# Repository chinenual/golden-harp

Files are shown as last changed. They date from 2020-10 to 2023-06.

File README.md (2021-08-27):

An updated interface to [Iasos's](https://iasos.com/)
["Golden Harp"](https://www.youtube.com/watch?v=cd00t0UGsC0).

The golden harp hardware was built by a now-defunct company named
UME.  It consisted of a small keyboard with two touch
sensitive strips which the musician can stroke like strumming a harp.
Output from this controller was fed through a proprietary serial
connection to a Commodore 64 where the signals were mapped to MIDI
notes with configurable key, octave and scale settings.

This project replaces the C64 based processing with an Arduino based
adapter.  Scales can be configured and uploaded to the adapter via a
Windows application (which need not be connected to the adapter during
performance). 

Thanks to Don Miller (@no-carrier) for reverse engineering the serial 
interface to the harp controller and creating the first Arduino implementation
to validate the controller serial interface.

Original implementation was a Commodore 64 program by Richard Wolton whose 
source code is lost in the mists of time.

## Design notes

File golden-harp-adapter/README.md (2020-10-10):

The Arduino device reads serial data from the harp controller (keyboard) and converts it to MIDI.

In performance mode, it need not be connected to a Windows machine; the USB port can be used as its power supply.

Notes pressed on either of the touch sensitive strips are converted to MIDI note on/off events at a fixed velocity of 64. The note conversion depends on the active key/scale/octave settings.

Those settings are selected from whatever presets are loaded and which can be changed via the keyboard on the controller.

In the studio, the Windows-based scale-manager.exe can connect through the USB port to configure scale presets.

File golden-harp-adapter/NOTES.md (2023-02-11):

Serial port names on Steve's mac:

board2: /dev/cu.usbserial-AG0JV596 (first box sent to Iasos)
board3: /dev/cu.usbserial-AG0JV6J0 (second box sent to Iasos)
board4: /dev/cu.usbserial-AG0JV27K (spare board for testing/support)
uno:    /dev/cu.usbserial-AL05OC8S (prototype)

Required libraries:
    ArduinoJson.h - https://arduinojson.org/
    SendOnlySoftwareSerial.h - https://github.com/nickgammon/SendOnlySoftwareSerial

Arduino IDE setup for firmware upload: 
    Tools->Board Arduino Nano
    Tools->Processor ATmega328P (Old bootloader)

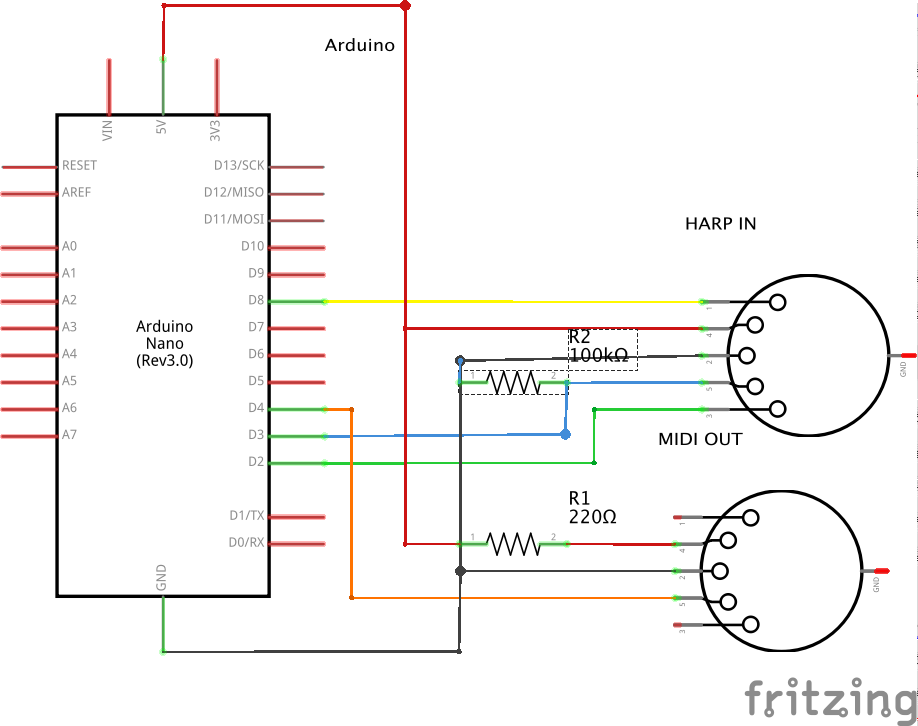
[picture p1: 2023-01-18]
golden-harp-adapter/nano-schematic_schem.png

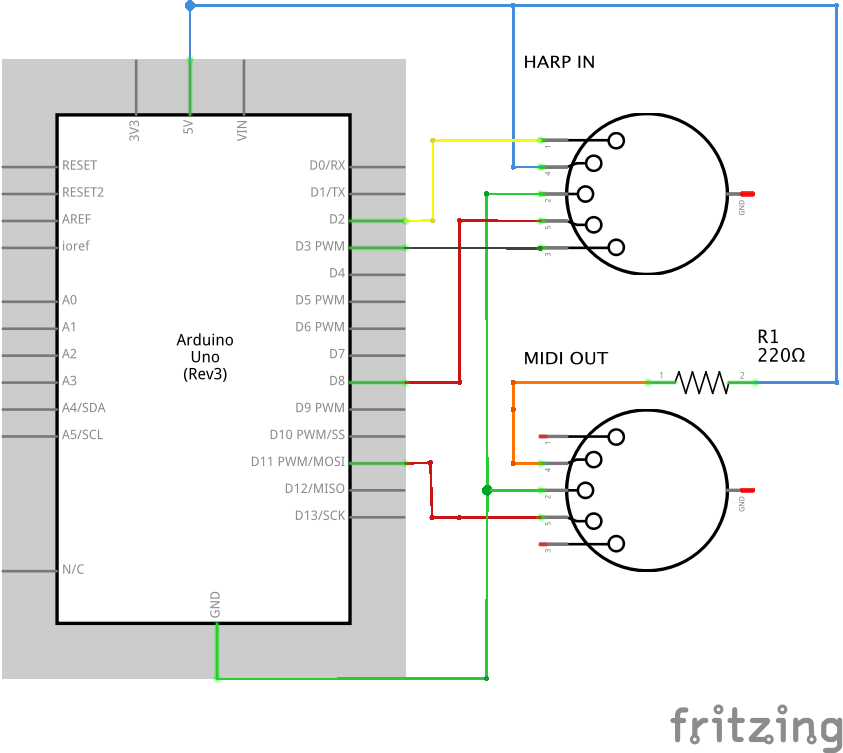
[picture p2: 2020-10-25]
golden-harp-adapter/uno-schematic.png

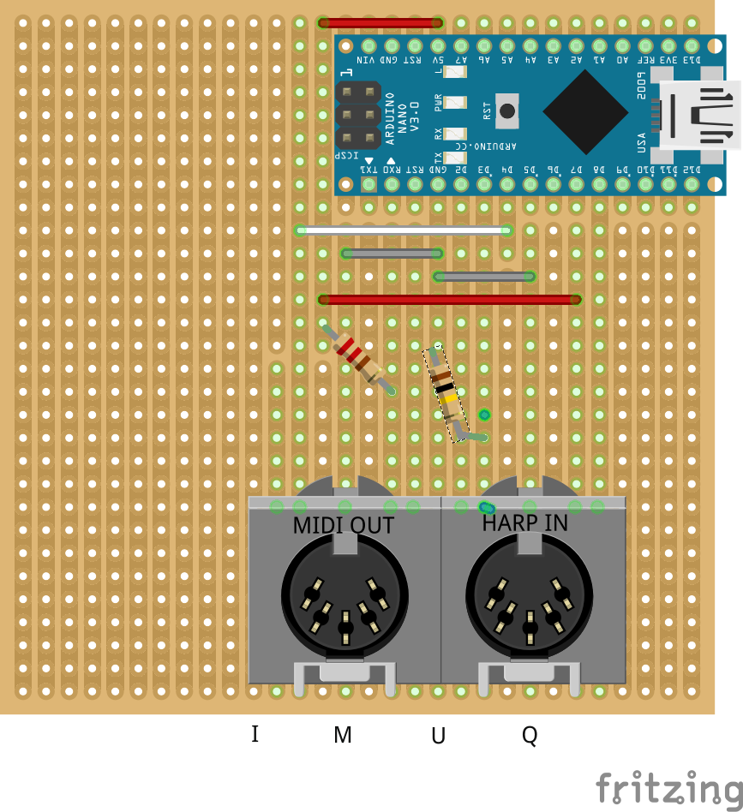
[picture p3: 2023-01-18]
golden-harp-adapter/stripboard_bb.png

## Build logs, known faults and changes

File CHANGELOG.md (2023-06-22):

## 1.5.1

Manager:

* Removes excessive delay on command read loop (speeds up setconfig considerably)

## 1.5.0

Manager:

* Reinitializes presets and scales vectors when reading a new config file.
* adds explicit error checks for JSON "status: ERROR" responses.

## 1.4.1

Adapter:

* Fixes the firmware upload script and re-versions the firmware

## 1.4.0

Manager:

* adds support for the new minnotelen param

Adapter:

* Added a pull down resistor to the Harp In serial connection
* min_note_length_ms parameter

## 1.3.0

Manager:

* Adds support for enabling debugging on the arduino 
* Serial config is now async via a goroutine so we can consume DEBUG stream
* Changes Excel parser from github.com/360EntSecGroup-Skylar/excelize to  github.com/uxri/excelize/v2 
 
 Adapter:
 
* Verbose debug mode

## 1.2.0

Manager:

* Invert the order of the presets in the Config XLS file to match the way Iasos views them when playing
* Tolerate presets in any order (use the Preset column to specify the preset number)

## 1.1.0

Manager:

* Support for new timing settings

Adapter: 

* make loop time and max_note_length_ms times configurable via the Manager

## 1.0.0

First release

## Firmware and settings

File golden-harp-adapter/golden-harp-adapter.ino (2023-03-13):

// pins for Harp Controller Keyboard DIN connector, left to right, back view, tab on top
// Nano/Stripboard version:
// 1 = D8 (DIN pin 1) LATCH
#define KBD_LATCH_PIN 8
// 2 = 5V   (DIN pin 4) 5V
// 3 = GND  (DIN pin 2) GND
// 4 = D3 (DIN pin 5) READ
#define KBD_READ_PIN 3
// 5 = D2 (DIN pin 3) CLOCK
#define KBD_CLOCK_PIN 2

// pins for the MIDI OUT connection, again, left to right, back view, tab on top
// Nano/Stripboard version:
// 2 = 5V  (DIN pin 4)  5V (via 220ohm resistor)
// 3 = GND (DIN pin 2)  GND 
// 4 = D4 (DIN pin 5)   DATA
#define MIDI_TX_PIN 4

#define CONFIG_IN_EEPROM 1
#define DEBUG_INPUT 0
#define VERBOSE_MIDI 0

#include "version.h"

#include <stddef.h> // for offsetof
#include <ArduinoJson.h>

#include <EEPROM.h>


// We assume a simple Arduino (e.g. Uno) with only a single UART TX/RX pair.   We use that connection for the USB connection
// to the host computer.   We use software serial for both MIDI and the keyboard controller connnection.

// we use EEPROM as non-volatile ram to store preset configuration between reboots
// my Uno development and the Nano "production" board supports 1024 bytes of EEPROM

#define MIDI_BAUD 31250
#define USB_BAUD  9600 // use low baud for the USB port in attempt to reduce interference with real-time MIDI


#define NOTE_ON_LED_PIN 13

// there are three distinct sets of "note" index values - I use the following terms to keep them from being confused:
//   HARDWARE_BYTE:  the bytes read from the serial connection that represent the raw hardware state of the keyboard
//   KEY_INDEX:      the index into the logic "strip" position or the musical keyboard
//   NOTE:           the scaled MIDI "note" value

// Key Indexes for the extent of the two strips and the musical keyboard:
#define MIN_R_STRIP 1           // "blue" 
#define MAX_R_STRIP 29          // "yellow"
#define MIN_L_STRIP 30          // labeled 1 on the keyboard
#define MAX_L_STRIP 56          // labeled 27 on the keyboard
#define MIN_MUSIC_KEYBOARD 60   // the leftmost C
#define MAX_MUSIC_KEYBOARD 96   // the rightmost C

#define MIDI_MIDDLE_C 60 // MIDI note value for middle-C
#define MIDI_VELOCITY 64

// cached loop_time value so we're not reading EEPROM every time around the loop
unsigned long loop_time_ms;
unsigned short min_note_length_ms;
unsigned short max_note_length_ms;

bool debug_enabled;
bool debug_midi_enabled;
bool debug_hw_enabled;

void setup()
{
  debug_enabled = false;
  debug_midi_enabled = false;
  debug_hw_enabled = false;

  Serial.begin(USB_BAUD);
//  Serial.println("# begin setup");

  usbconfig_setup();
  midi_setup();
  harpin_setup();
  config_setup(); 
  
//  Serial.println("# end setup");
}

void loop()
{
  unsigned long start = millis();

  usbconfig_loop();
  harpin_loop();

  unsigned long elapsed = millis() - start;
  if (elapsed < loop_time_ms) {
    delay(loop_time_ms - elapsed);
  }
}

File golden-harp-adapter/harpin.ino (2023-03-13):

// For the serial connection to the keyboard controller:
#include <avr/io.h>
#include <avr/interrupt.h>

#define NUM_KEYS 128

unsigned long key_state[NUM_KEYS];  // non-zero if we've sent an ON event for this key (timestamp of when we detected key-down)
boolean key_scan[NUM_KEYS];         // this key was depressed on the current scan


int hardware_to_key_table[NUM_KEYS] = {
  /// // key [byte-index, bit]

  -1,  //  0 [0, 0] // keystrips
  24,  //  1 [0, 1] //...
  25,  //  2 [0, 2]
  14,  //  3 [0, 3]
  23,  //  4 [0, 4]
  3,   //  5 [0, 5]
  4,   //  6 [0, 6]
  13,  //  7 [0, 7]

  -1,  //  8 [1, 0] // musical keyboard
  91,  //  9 [1, 1] //...
  75,  // 10 [1, 2]
  83,  // 11 [1, 3]
  -1,  // 12 [1, 4]
  -1,  // 13 [1, 5]
  -1,  // 14 [1, 6]
  67,  // 15 [1, 7]

  -1,  // 16 [2, 0] // musical keyboard
  85,  // 17 [2, 1] //...
  69,  // 18 [2, 2]
  77,  // 19 [2, 3]
  93,  // 20 [2, 4]
  -1,  // 21 [2, 5]
  -1,  // 22 [2, 6]
  61,  // 23 [2, 7]

  -1,  // 24 [3, 0] // musical keyboard
  90,  // 25 [3, 1] //...
  74,  // 26 [3, 2]
  82,  // 27 [3, 3]
  -1,  // 28 [3, 4]
  -1,  // 29 [3, 5]
  -1,  // 30 [3, 6]
  66,  // 31 [3, 7]

  -1,  // 32 [4, 0] // musical keyboard
  89,  // 33 [4, 1] //...
  73,  // 34 [4, 2]
  81,  // 35 [4, 3]
  -1,  // 36 [4, 4]
  -1,  // 37 [4, 5]
  -1,  // 38 [4, 6]
  65,  // 39 [4, 7]

  -1,  // 40 [5, 0] // musical keyboard
  88,  // 41 [5, 1] //...
  72,  // 42 [5, 2]
  80,  // 43 [5, 3]
  96,  // 44 [5, 4]
  -1,  // 45 [5, 5]
  -1,  // 46 [5, 6]
  64,  // 47 [5, 7]

  -1,  // 48 [6, 0] // musical keyboard
  86,  // 49 [6, 1] //...
  70,  // 50 [6, 2]
  78,  // 51 [6, 3]
  94,  // 52 [6, 4]
  -1,  // 53 [6, 5]
  -1,  // 54 [6, 6]
  62,  // 55 [6, 7]

  -1,  // 56 [7, 0] // musical keyboard
  87,  // 57 [7, 1] //...
  71,  // 58 [7, 2]
  79,  // 59 [7, 3]
  95,  // 60 [7, 4]
  -1,  // 61 [7, 5]
  -1,  // 62 [7, 6]
  63,  // 63 [7, 7]

  -1,  // 64 [8, 0] // musical keyboard
  84,  // 65 [8, 1] //...
  68,  // 66 [8, 2]
  76,  // 67 [8, 3]
  92,  // 68 [8, 4]
  -1,  // 69 [8, 5]
  -1,  // 70 [8, 6]
  60,  // 71 [8, 7]

  -1,  // 72 [9, 0] // keystrips
  22,  // 73 [9, 1] //..
  27,  // 74 [9, 2]
  12,  // 75 [9, 3]
  21,  // 76 [9, 4]
  5,   // 77 [9, 5]
  6,   // 78 [9, 6]
  11,  // 79 [9, 7]

  -1,  // 80 [10, 0] // keystrips
  51,  // 81 [10, 1] //..
  55,  // 82 [10, 2]
  41,  // 83 [10, 3]
  50,  // 84 [10, 4]
  34,  // 85 [10, 5]
  35,  // 86 [10, 6]
  40,  // 87 [10, 7]

  -1,  // 88 [11, 0] // keystrips
  53,  // 89 [11, 1] //..
  54,  // 90 [11, 2]
  39,  // 91 [11, 3]
  52,  // 92 [11, 4]
  36,  // 93 [11, 5]
  37,  // 94 [11, 6]
  38,  // 95 [11, 7]

  -1,  // 96 [12, 0] // keystrips
  18,  // 97 [12, 1] //..
  29,  // 98 [12, 2]
  16,  // 99 [12, 3]
  17,  // 100 [12, 4]
  30,  // 101 [12, 5]
  31,  // 102 [12, 6]
  15,  // 103 [12, 7]

  -1,  // 104 [13, 0] // keystrips
  49,  // 105 [13, 1] //..
  56,  // 106 [13, 2]
  43,  // 107 [13, 3]
  48,  // 108 [13, 4]
  32,  // 109 [13, 5]
  33,  // 110 [13, 6]
  42,  // 111 [13, 7]

  -1,  // 112 [14, 0] // keystrips
  20,  // 113 [14, 1] //..
  28,  // 114 [14, 2]
  10,  // 115 [14, 3]
  19,  // 116 [14, 4]
  7,   // 117 [14, 5]
  8,   // 118 [14, 6]
  9,   // 119 [14, 7]

  -1,  // 120 [15, 0] // keystrips
  47,  // 121 [15, 1] //..
  26,  // 122 [15, 2]
  45,  // 123 [15, 3]
  46,  // 124 [15, 4]
  1,   // 125 [15, 5]
  2,   // 126 [15, 6]
  44,  // 127  [15, 7]
};

// Strips mapping - selected values to sanity check the original strip-only mapping table
//  30: LMIN:  0:0:0:0:0:0:0:0:0:0:0:0:32:0:0:0:  [12 - 32] -> 32+bits -> 32+5 = 37 (sparse variant) new variant: 101
//  56: LMAX: 0:0:0:0:0:0:0:0:0:0:0:0:0:4:0:0:    [13 - 4]  -> 40+bits -> 40+2 = 42
//  1:  RMIN: 0:0:0:0:0:0:0:0:0:0:0:0:0:0:0:32:   [15 - 32] -> 56+bits -> 56+5 = 61
//  28: RMAX-1: 0:0:0:0:0:0:0:0:0:0:0:0:0:0:4:0:  [14 - 4]  -> 48+bits -> 48+2 = 50
//  29: RMAX:  0:0:0:0:0:0:0:0:0:0:0:0:4:0:0:0:   [12 - 4]  -> 32+bits -> 32+2 = 34

// Musical Keyboard mapping
// my test hardware has some missing keys - I am guessing values based on the patterns I see in the non-missing ones:
//                                            [index - value]
//   60: C0:  0:0:0:0:0:0:0:0:128:0:0:0:0:0:0:0:  [8 - 128] 8*8+7 =>
//   61: Db0: 0:0:128:0:0:0:0:0:0:0:0:0:0:0:0:0:  [2 - 128]
//   62: D0:  (missing key)                       [6 - 128]  : GUESS
//   63: Eb0: 0:0:0:0:0:0:0:128:0:0:0:0:0:0:0:0:  [7 - 128]
//   64: E0:  (missing key)                       [5 - 128]  : GUESS
//   65: F0:  0:0:0:0:128:0:0:0:0:0:0:0:0:0:0:0:  [4 - 128]
//   66: Gb0: 0:0:0:128:0:0:0:0:0:0:0:0:0:0:0:0:  [3 - 128]
//   67: G0:  0:128:0:0:0:0:0:0:0:0:0:0:0:0:0:0:  [1 - 128]
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

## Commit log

2020-10-07 Don Millers original code
    [schematic.fzz]
2020-10-07 wire colors to match Iasos hardware
    [schematic.fzz]
2020-10-10 sample winc file
2020-10-20 rename dir for compatibility with Arduino IDE
    [schematic.fzz]
2020-10-21 fix initialization of the input data
    [golden-harp-adapter.ino]
2020-10-21 predict missing musical key values
    [golden-harp-adapter.ino]
2020-10-22 preliminary MIDI support
    [schematic.fzz]
2020-10-25 fix MIDI wiring diagram
    [schematic.fzz]
2020-10-26 match pin mapping comments to diagram and clarify pin numbers; use SendOnlySoftSerial, run USB at 9600
2020-10-26 fix glitchy MIDI by slowing down the controller scan to once every 20ms
    [golden-harp-adapter.ino]
2020-10-26 fix scale init buffer overflow
    [golden-harp-adapter.ino]
2020-10-26 define 2 presets and support switching between them
2020-10-30 prototype excel based config
    [HarpConfig.xlsx]
2020-10-31 turn on/off onboard LED to indicate "note playing"
2020-11-04 new xlsx file format
    [HarpConfig.xlsx]
2020-11-04 parse transpose roots
    [HarpConfig.xlsx]
2020-11-04 pack scales
    [HarpConfig.xlsx]
2020-11-05 JSON over usb
    [nano-schematic.fzz, uno-schematic.fzz]
2020-11-09 updated schematic and stripboard design
    [nano-schematic.fzz, stripboard.fzz]
2020-11-10 switch to new nano/stripboard pin assignments; use digitalRead (seems fast enough) rather than port banging
2020-11-10 off by one init error for the scaling vectors; use new key-based preset config
    [config.ino]
2020-11-10 fix preset usb config
    [config.ino, usbconfig.ino]
2020-11-10 reintroduce the ui prototype
2020-11-10 wire up main in prep for ui
2020-11-12 ui can now set and get config from the arduino
2020-11-12 fix preset key label to match config file
    [HarpConfig.xlsx]
2020-11-14 yet another set of pin changes - physical stripboard didnt line up as planned (had to shift the DIN connectors)
    [HarpConfig.xlsx, stripboard.fzz]
2020-11-19 2nd board design - tested and works
    [nano-schematic.fzz, stripboard.fzz]
2020-11-21 manage version numbers for both the firmware and scale manager
    [stripboard.fzz]
2020-11-22 basic UI works
    [HarpConfig.xlsx]
2023-01-08 debug logging
    [HarpConfig.xlsx]
2023-01-18 update circuit diagrams
    [nano-schematic.fzz, stripboard.fzz]
